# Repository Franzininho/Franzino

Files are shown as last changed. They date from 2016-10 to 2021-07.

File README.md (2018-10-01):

# Franzino (ENG)

Franzino is a low cost Arduino standalone board. As its name suggests, is a simple board that has just the basic components so you can use the ATmega328P microcontroller, both for study and for applications in projects.

Unlike standalones available in the market, the Franzino board has pinout Arduino Rev 3 and connector for easy connection of the serial interface. The ease of access to the pins of the serial interface, enables you to connect communication modules according to the needs of the project. You will be able to easily connect serial level converters such as USB, RS232, RS485 and even a Bluetooth module, without the need to use shields.

Franzino uses Arduino UNO bootloader to facilitating the upload process of your scketch. You can easily upload your sketch to Franzino board using a USB to Serial converter, following the same steps that are already used to your Arduino UNO board.

# Characteristics:

- Arduino UNO R3 pinout;
- ATmega328P Microcontroller;
- Power: 7.5 V to 20 V DC;
- Protection against reverse polarity of the supply;
- Connector for serial interface connection;
- Power on LED;
- LED connected to pin 13 for general porpouse;

# Franzino (PT)

A placa Franzino é um Arduino standalone de baixo custo. Como seu próprio nome sugere, é uma placa enxuta que possui os componentes básicos para que você possa usar o microcontrolador ATmega328, tanto para estudo quanto para a aplicações em projetos.

Diferente dos standalones disponíveis no mercado, a placa Franzino possui pinagem Arduino UNO Rev 3 e conector para fácil ligação da interface serial. A facilidade de acesso aos pinos da interface serial, possibilita que você ligue módulos de comunicação conforme a necessidade do projeto. Você conseguirá facilmente ligar conversores de níveis seriais como: USB, RS232, RS485 e até mesmo um módulo Bluetooth, sem a necessidade do uso de shields.

A Franzino usa o bootloader do Arduino UNO facilitando o processo de upload do seu scketch. Você poderá facilmente fazer o upload do seu sketch para placa usando um conversor USB/Serial, seguindo os mesmos passos que já está acostumado a fazer com a placa Arduino UNO.

## Características:

- Pinagem Padrão UNO R3
- Microcontrolador ATmega328P;
- Alimentação: 7,5 V a 20 V DC;
- Proteção contra inversão de polaridade da fonte;
- Conector para ligação de interface serial;
- LED para indicação de alimentação;
- LED conectado ao pino 13 para uso geral

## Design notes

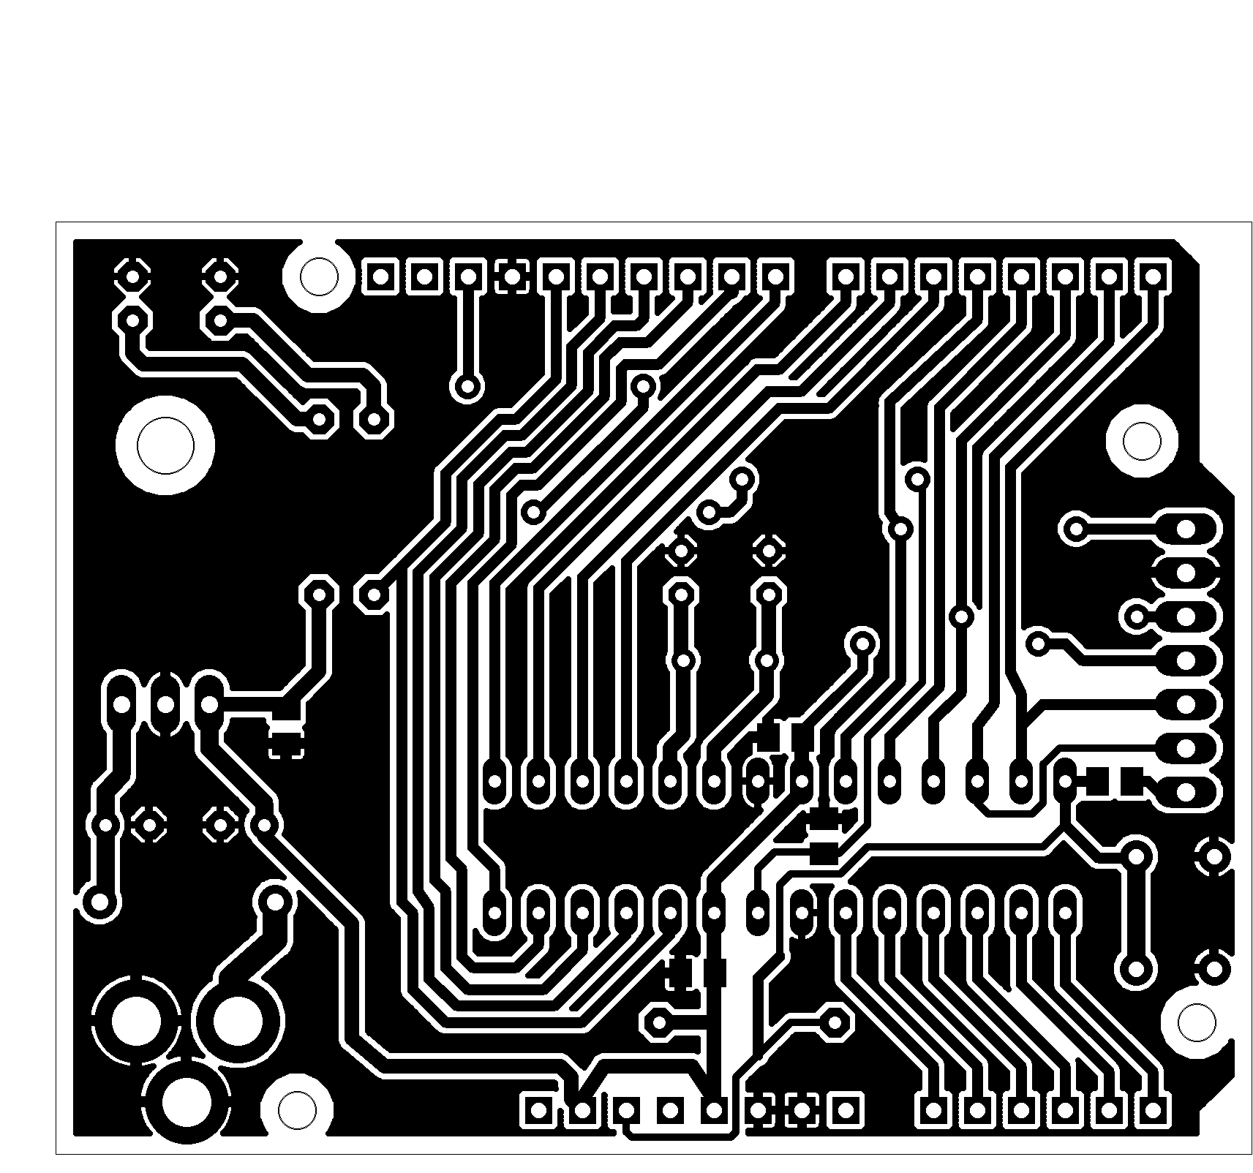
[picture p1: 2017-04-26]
Franzino - Eagle/RV0/Franzino_trilhas.png

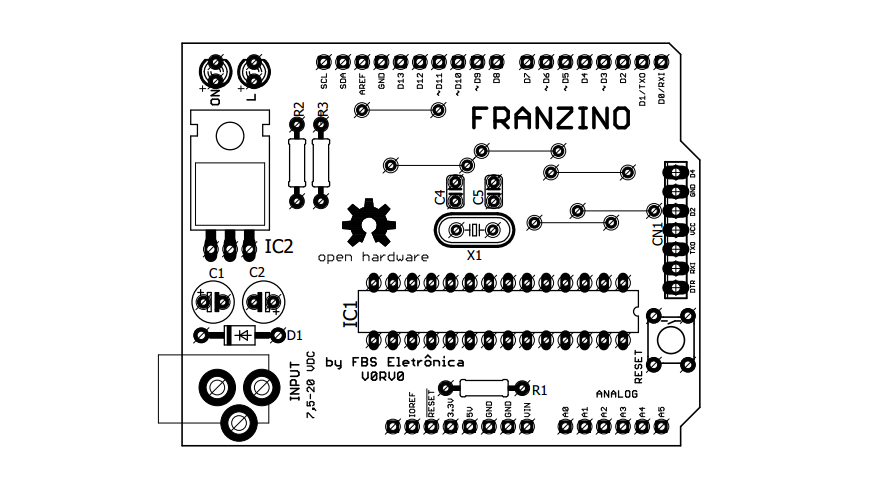
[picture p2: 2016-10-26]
Franzino - Eagle/RV0/franzino.png

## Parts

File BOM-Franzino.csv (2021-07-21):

Placa |  | Franzino
Referência | Componente | quantidade | Valor
C1 | 10uF X 50V | 1
C2 | 10uF X 50V | 1
C3 | 100nF SMD 0805 | 1
C4 | 22pF | 1
C5 | 22pF | 1
C6 | 100nF SMD 0805 | 1
C7 | 100nF SMD 0806 | 1
C8 | 100nF SMD 0807 | 1
C9 | 100nF SMD 0808 | 1
CN1 | Barra de pinos 7 vias 90° | 1
D1 | 1n4007 | 1
IC1 | Soquete 28 pinos | 1
IC2 | Regulador 7805 | 1
J1 | mini header simples 40 pinos | 1
JP1 | JUMPER FIO 10 mm | 1
JP2 | JUMPER FIO 10 mm | 1
JP3 | JUMPER FIO 10 mm | 1
JP4 | JUMPER FIO 10 mm | 1
JP5 | JUMPER FIO 10 mm | 1
JP6 | JUMPER FIO 10 mm | 1
L | LED 3 mm VERDE | 1
ON | LED 3 mm Amarelo | 1
P1 | JACK 2,1 mm | 1
R1 | Resistor 10 K 5% | 1
R2 | Resistor 1 K 5% | 1
R3 | Resistor 1 K 5% | 1
RESET | Chave Tactil 7 mm | 1
X1 | Cristal 16 MHz | 1
PCB | Placa de circuito impresso Franzino | 1

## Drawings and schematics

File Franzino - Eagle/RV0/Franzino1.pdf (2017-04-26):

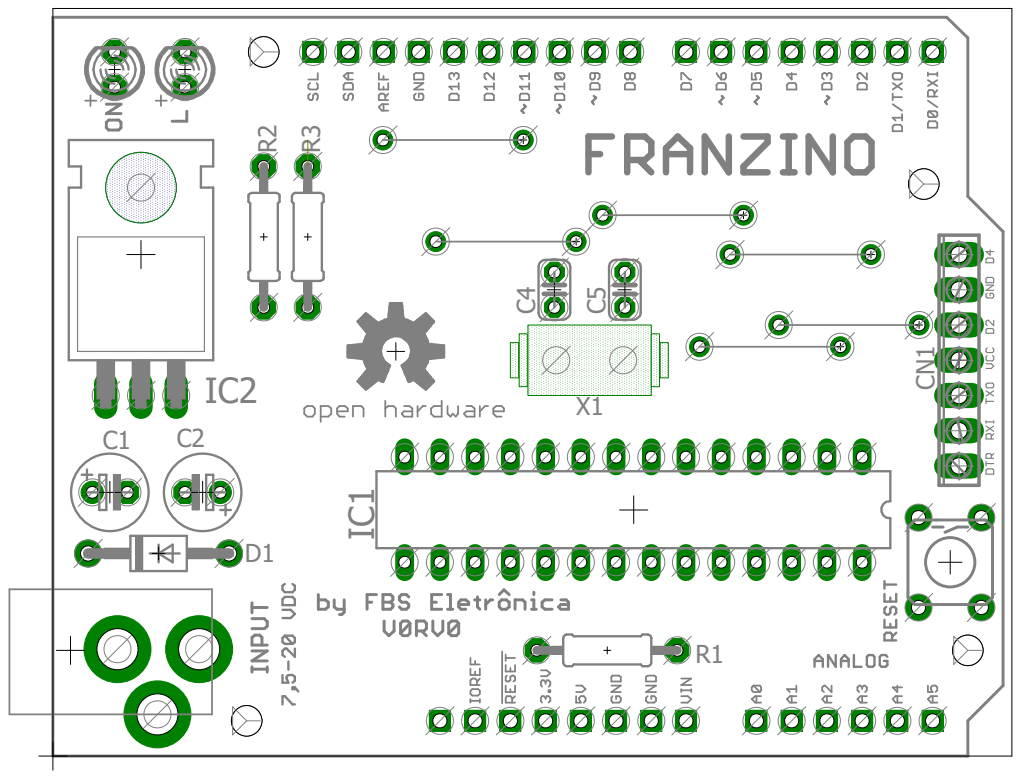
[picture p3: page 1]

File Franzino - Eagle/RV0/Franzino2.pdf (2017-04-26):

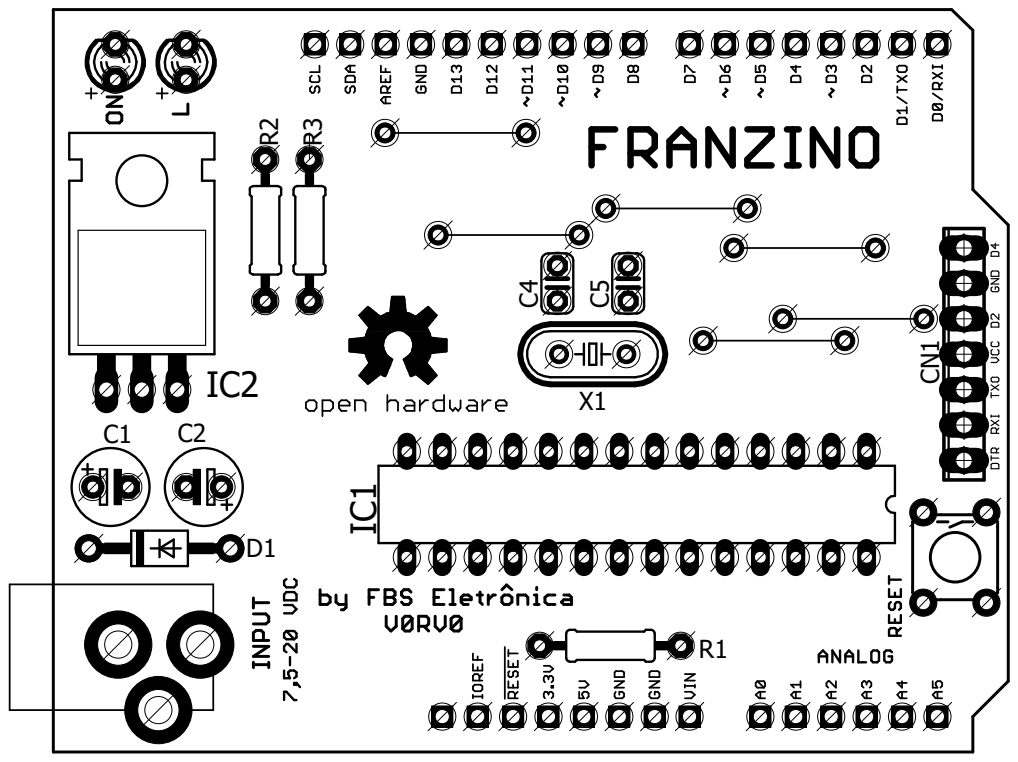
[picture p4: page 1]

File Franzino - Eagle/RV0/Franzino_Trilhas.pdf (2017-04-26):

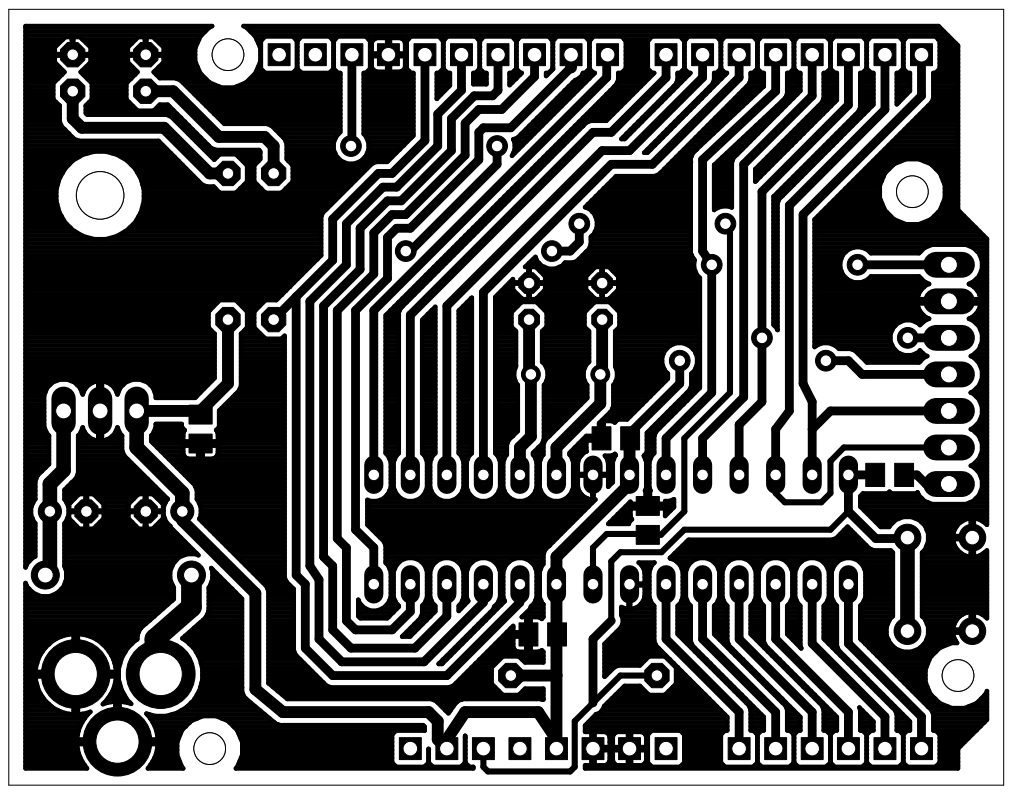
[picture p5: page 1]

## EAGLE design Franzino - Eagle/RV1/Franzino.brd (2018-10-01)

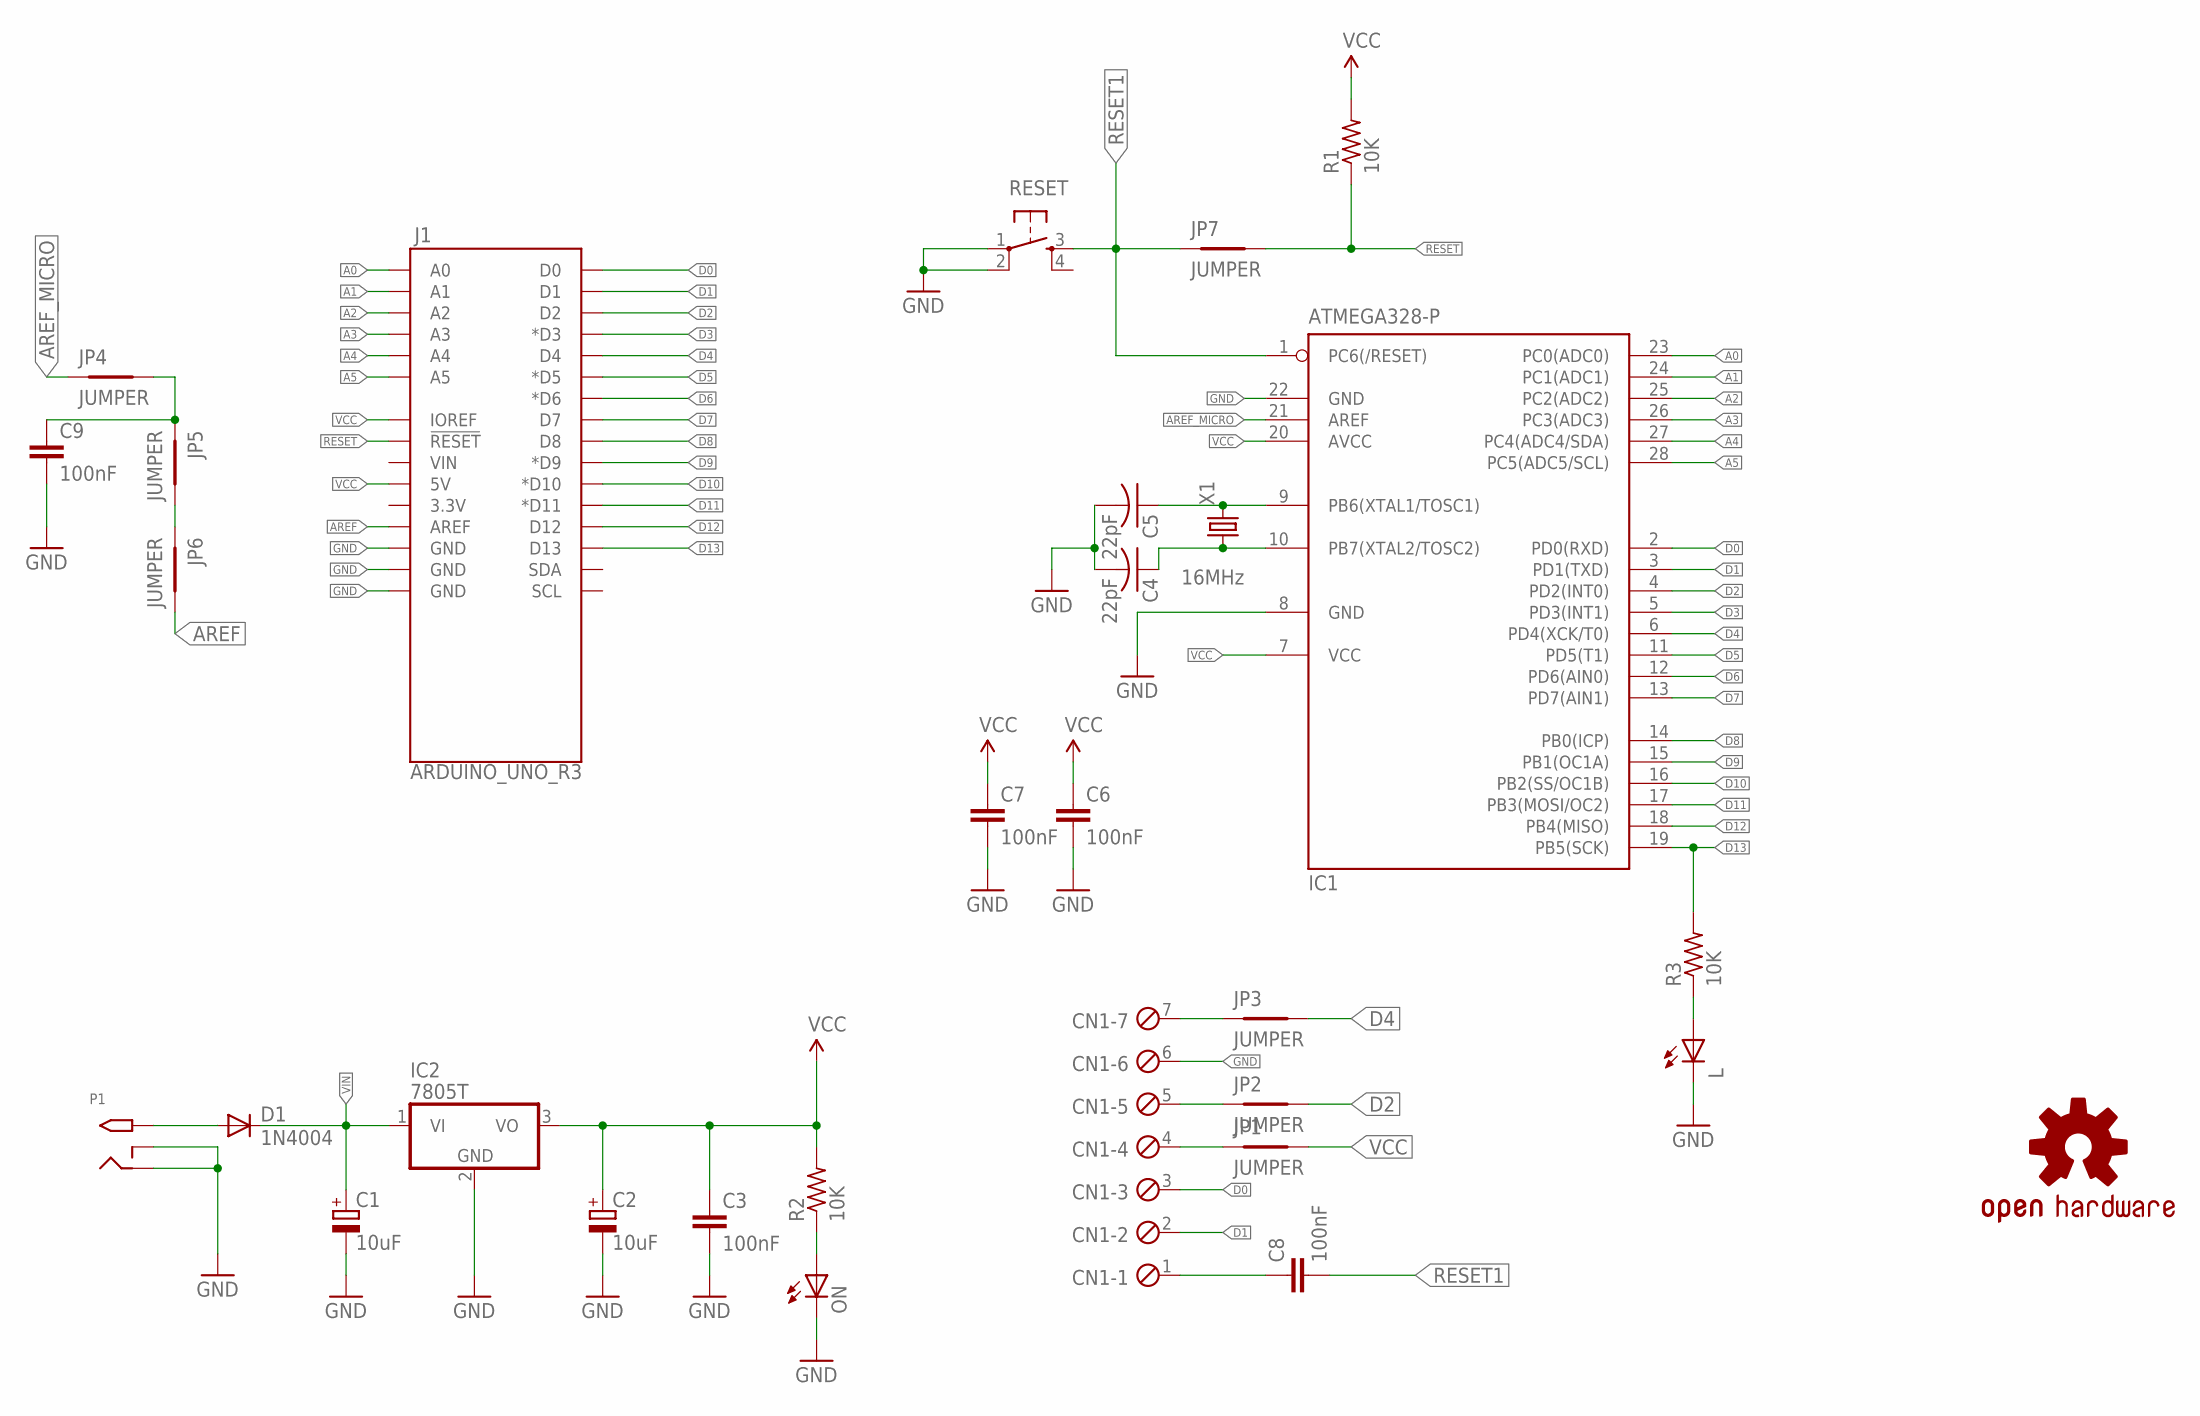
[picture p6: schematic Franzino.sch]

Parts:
C1, C2: 10uF; E2,5-6
C3, C6, C7, C8, C9: 100nF; C025-025X050
C4, C5: 22pF; C025-024X044
CN1: BARRA de PINOS 6 VIAS; 7POL254
D1: 1N4004; DO41-10
IC1: ATMEGA328-P; DIL28-3
IC2: 7805T; TO220H
J1: ARDUINO_UNO_R3; ARDUINO_UNO_R3_PINS
JP1, JP2, JP3, JP4, JP5, JP6, JP7: JUMPER; JUMP10
L: LED 3mm Amarelo; LED3MM
LOGO2: OSHW-LOGOL; OSHW-LOGO-L
ON: LED 3 mm VERDE; LED3MM
P1: 2.1MMJACKTHM; PJ-102A
R1, R2, R3: 10K; 0207/10
RESET: CHAVE TACTIL 6 mm; TACTILE-PTH
X1: 16MHz; HC49/S

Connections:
A0: IC1.23 (PC0(ADC0)), J1.A0
A1: IC1.24 (PC1(ADC1)), J1.A1
A2: IC1.25 (PC2(ADC2)), J1.A2
A3: IC1.26 (PC3(ADC3)), J1.A3
A4: IC1.27 (PC4(ADC4/SDA)), J1.A4
A5: IC1.28 (PC5(ADC5/SCL)), J1.A5
AREF: J1.AREF, JP6.2
AREF_MICRO: IC1.21 (AREF), JP4.1
D0: CN1.3, IC1.2 (PD0(RXD)), J1.D0
D1: CN1.2, IC1.3 (PD1(TXD)), J1.D1
D2: IC1.4 (PD2(INT0)), J1.D2, JP2.2
D3: IC1.5 (PD3(INT1)), J1.D3 (*D3)
D4: IC1.6 (PD4(XCK/T0)), J1.D4, JP3.2
D5: IC1.11 (PD5(T1)), J1.D5 (*D5)
D6: IC1.12 (PD6(AIN0)), J1.D6 (*D6)
D7: IC1.13 (PD7(AIN1)), J1.D7
D8: IC1.14 (PB0(ICP)), J1.D8
D9: IC1.15 (PB1(OC1A)), J1.D9 (*D9)
D10: IC1.16 (PB2(SS/OC1B)), J1.D10 (*D10)
D11: IC1.17 (PB3(MOSI/OC2)), J1.D11 (*D11)
D12: IC1.18 (PB4(MISO)), J1.D12
D13: IC1.19 (PB5(SCK)), J1.D13, R3.2
GND: C1.-, C2.-, C3.2, C4.2, C5.2, C6.2, C7.2, C9.2, CN1.6, IC1.8 (GND), IC1.22 (GND), IC2.2 (GND), J1.GND@1 (GND), J1.GND@2 (GND), J1.GND@3 (GND), L.K (C), ON.K (C), P1.RING, P1.RING_SW, RESET.1, RESET.2
unnamed: D1.A, P1.TIP
unnamed: L.A, R3.1
unnamed: C8.1, CN1.1
unnamed: CN1.4, JP1.1
unnamed: CN1.5, JP2.1
unnamed: ON.A, R2.1
unnamed: CN1.7, JP3.1
unnamed: C5.1, IC1.9 (PB6(XTAL1/TOSC1)), X1.2
unnamed: C4.1, IC1.10 (PB7(XTAL2/TOSC2)), X1.1
unnamed: C9.1, JP4.2, JP5.1
unnamed: JP5.2, JP6.1
RESET: J1.RESET@1 (!RESET!), JP7.2, R1.1
RESET1: C8.2, IC1.1 (PC6(/RESET)), JP7.1, RESET.3
VCC: C2.+, C3.1, C6.1, C7.1, IC1.7 (VCC), IC1.20 (AVCC), IC2.3 (VO), J1.5V, J1.IOREF, JP1.2, R1.2, R2.2
VIN: C1.+, D1.C, IC2.1 (VI)

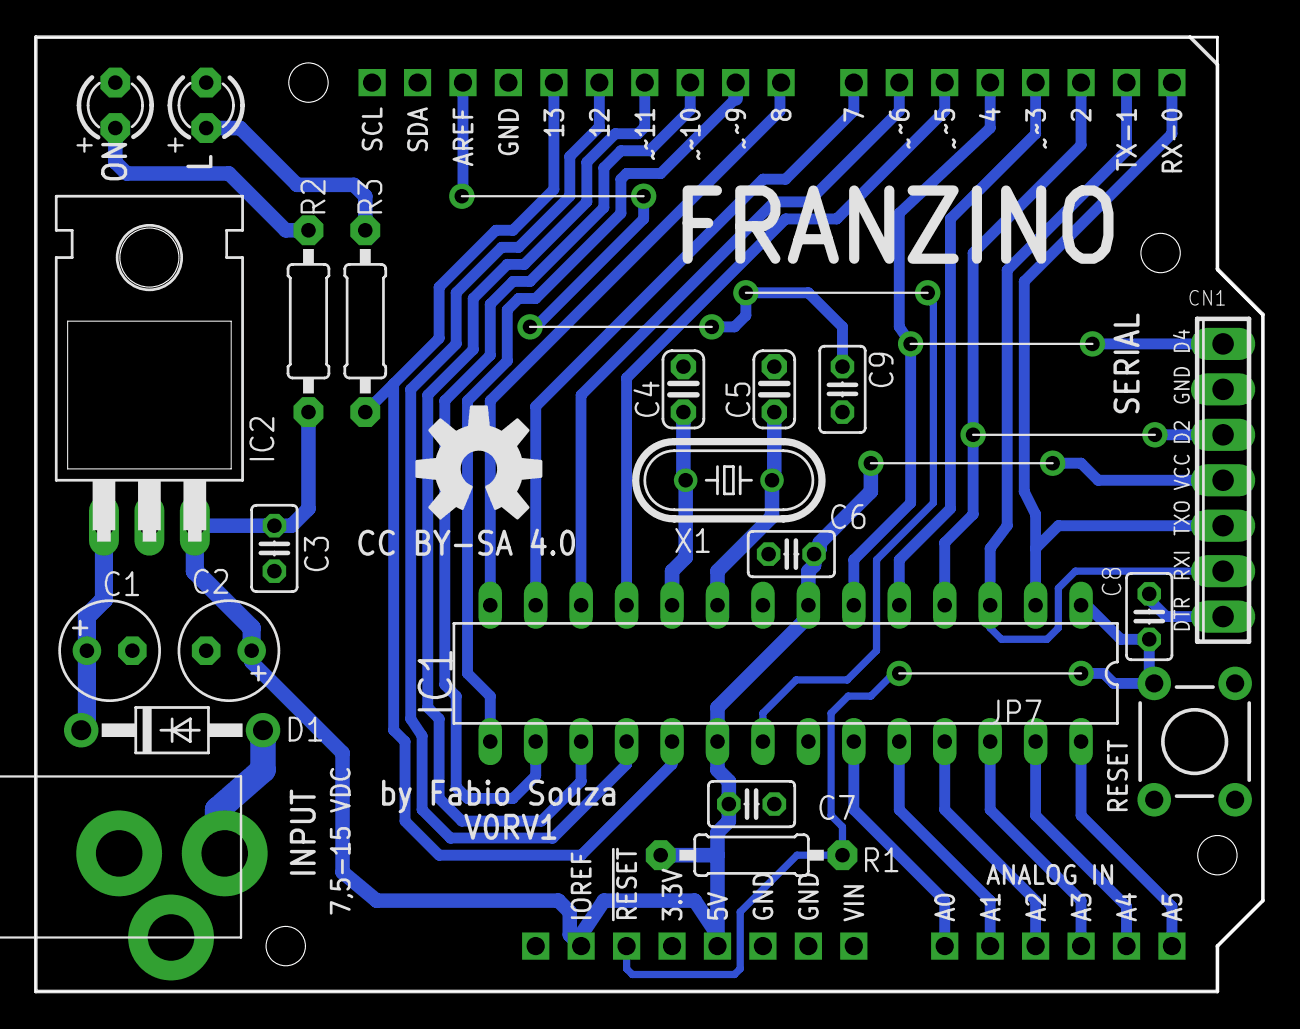
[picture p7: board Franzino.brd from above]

Board: 2 copper layers, 68.6 x 53.3 mm, 30 parts (0 on the bottom side), 38 nets.

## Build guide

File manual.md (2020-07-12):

Franzino

by Fábio Souza

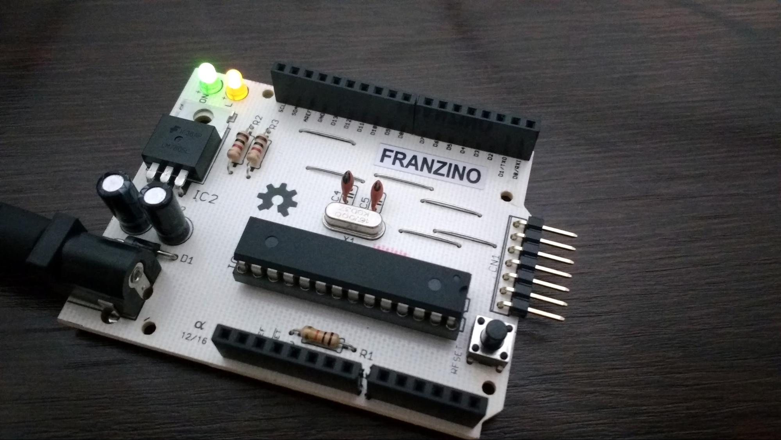
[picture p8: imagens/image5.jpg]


A placa Franzino é um Arduino standalone de baixo custo. Como seu próprio nome sugere, é uma placa enxuta que possui os componentes básicos para que você possa usar o microcontrolador ATmega328, tanto para estudo quanto para a aplicações em projetos.

Diferente dos standalones disponíveis no mercado, a placa Franzino possui pinagem Arduino UNO Rev 3 e conector para fácil ligação da interface serial. A facilidade de acesso aos pinos da interface serial, possibilita que você ligue módulos de comunicação conforme a necessidade do projeto. Você conseguirá facilmente ligar conversores de níveis seriais como: USB, RS232, RS485 e até mesmo um módulo Bluetooth, sem a necessidade do uso de shields.

A Franzino vem com o bootloader do Arduino UNO facilitando o processo de upload do seu scketch. Você poderá facilmente fazer o upload do seu sketch para placa usando um conversor USB/Serial, seguindo os mesmos passos que já está acostumado a fazer com a placa Arduino UNO.

## Características:

- Pinagem Padrão UNO R3
- Microcontrolador ATmega328P;
- Alimentação: 7,5 V a 20 V DC;
- Proteção contra inversão de polaridade da fonte;
- Conector para ligação de interface serial;
- LED para indicação de alimentação;
- LED conectado ao pino 13 para uso geral

A seguir é apresentada a pinagem para interface serial:

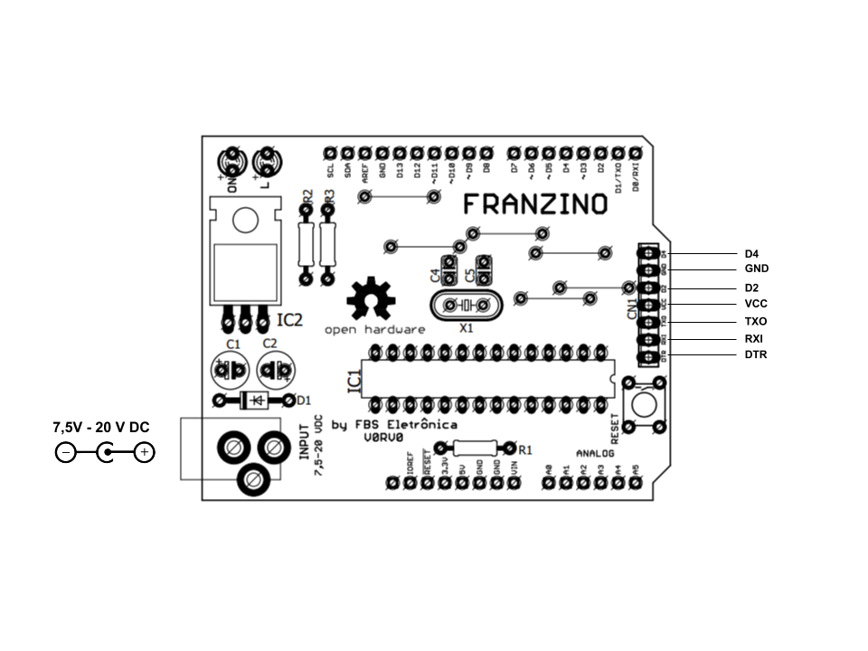
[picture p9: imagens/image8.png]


Os pino D2 e D4 podem ser utilizados para uma comunicação soft serial, como pino de controle da comunicação RS485 ou outras aplicações de entrada ou saída.

Outra vantagem interessante é que as linhas de alimentação(VCC e GND) também estão disponíveis nesse conector.

Assim, com esse conector você pode facilmente ligar um  conversor USB/Serial para comunicação com um computador, seja para upload dos sketchs quanto para troca de informações.

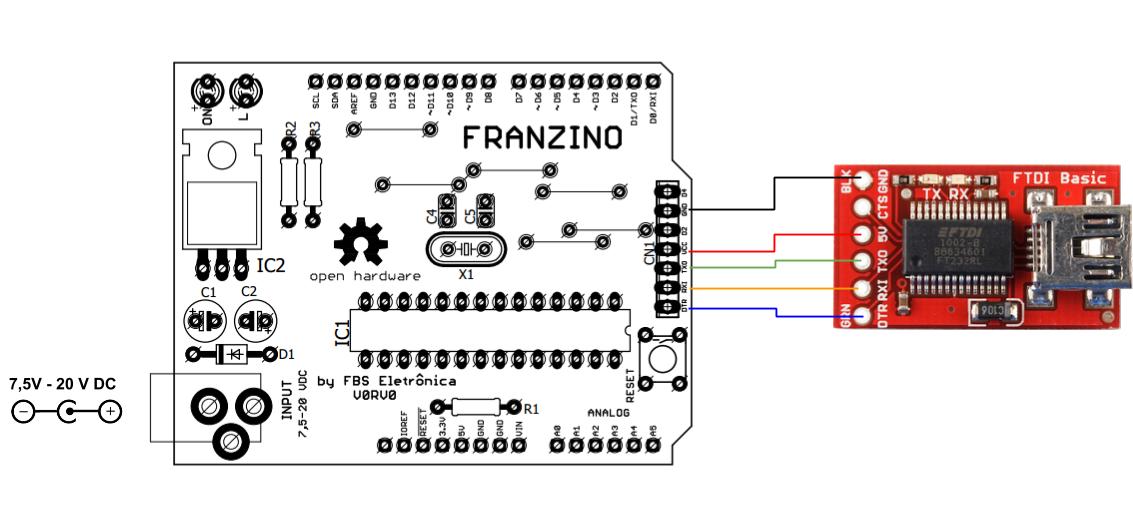
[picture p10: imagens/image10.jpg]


Se o seu projeto não necessitar da comunicação USB/Serial durante o seu funcionamento, você poderá usar o mesmo conversor para fazer upload em outra Franzinos.

Algumas aplicações necessitam de comunicação serial no padrão RS232. Dessa forma você pode ligar facilmente um conversor TTL/RS232.

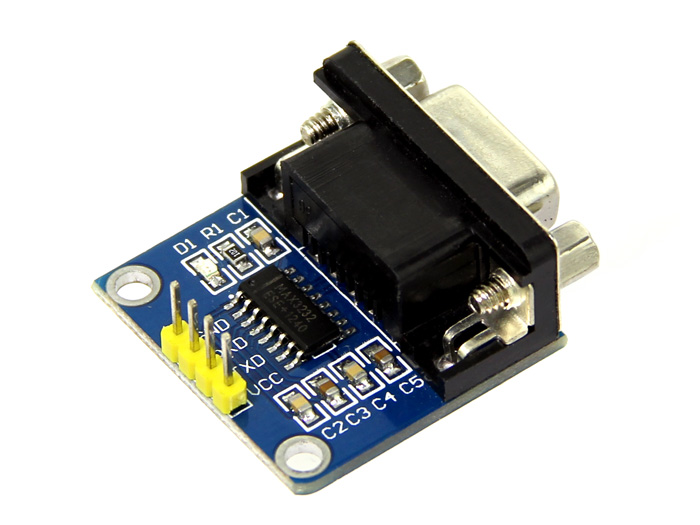
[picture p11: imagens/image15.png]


Também é comum aplicações que necessitem da comunicação RS485. Para isso você pode facilmente ligar um módulo conversor TTL/RS485:

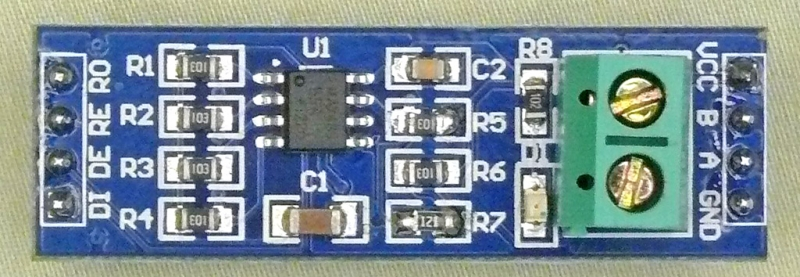
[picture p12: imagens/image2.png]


Outra aplicação interessante para comunicação e o uso de módulos Bluetooth. Esse tipo de módulo pode ser facilmente ligado a Franzino tanto para uso dos pinos padrões de comunicação TX e RX quanto para comunicação soft serial:

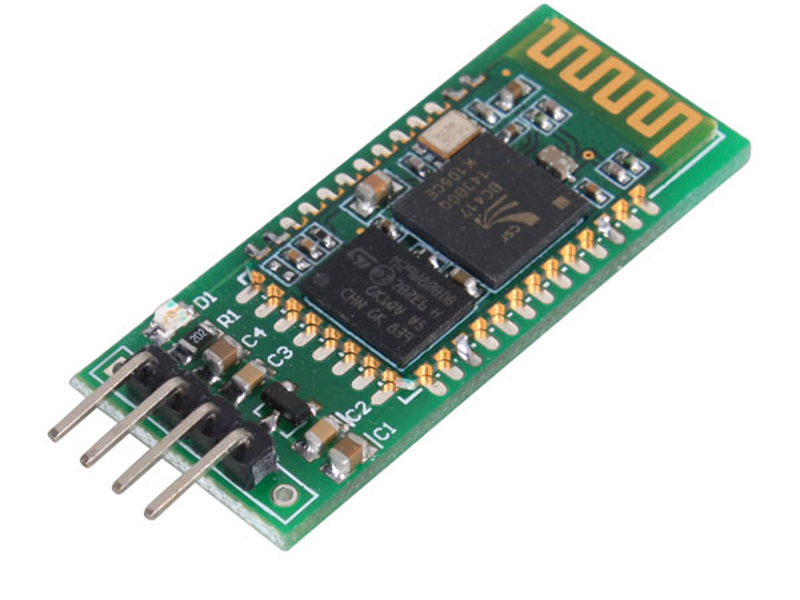
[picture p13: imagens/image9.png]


Como observado acima, há muitas possibilidades de comunicações e você pode facilmente ligar outros módulos para diversas aplicações conforme sua necessidade.

## Limitações da Franzino

A Franzino é uma placa standalone que possui diversas vantagens. Porém como foi desenvolvida em face simples e com o mínimo de componente necessários para o uso do microcontrolador, possui algumas limitações em relação ao Arduino UNO, que são:

- Não há regulador 3,3 V, dessa forma o pino 3.3V não está conectado;
- O pino Vin não está conectado a alimentação;
- Os pinos SCL e SDA não estão conectados as pinos A4 e A5;
- Não possui conversor USB/Serial
- Precisa de um conversor USB/Serial para upload dos sketchs

## Alimentação

A Franzino pode ser alimentada das seguintes formas:

- Conector P4 com tensão de 7,5 V a 20 V como positivo no centro;
- Pino 5V e GND - tensão de alimentação fixa em 5 VDC
- Através nos pinos VCC e GND disponíveis conector de expansão serial;

### Atenção

Não LIGAR o VCC do conversor USB/SERIAL a placa se a fonte externa estiver ligada. Nesse caso ligar apenas os pinos DTR, RXI, TXO e GND.

## Blink com a Franzino

Upload via conversor USB/SERIAL

Para fazer o famoso blink com a Franzino, primeiro é necessário ligar o conversor USB/Serial a placa, como exibido na figura abaixo:



Selecione na IDE do Arduino a Placa Arduino/Genuino UNO. Também selecione a porta COM que foi criada ao ser inserido o conversor USB/SERIAL:

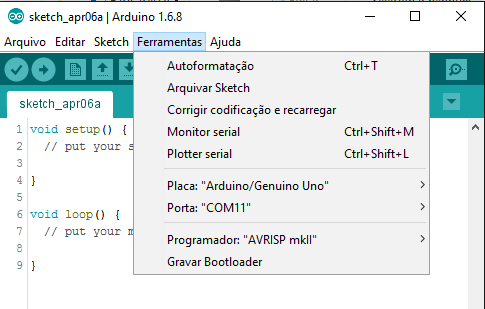
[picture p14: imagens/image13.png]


Faça o UPLOAD:

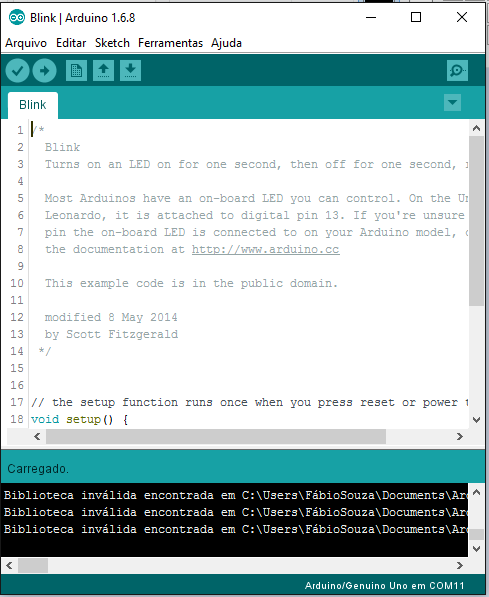
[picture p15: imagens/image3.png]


## Gravando a Franzino com um placa Arduino UNO

Se você não possui um conversor USB/Serial você pode gravar a Franzino através de um Arduino. Para isso vamos configurar a placa Arduino UNO com programador.

Escolha a opção ArduinoISP, conforme figura abaixo:

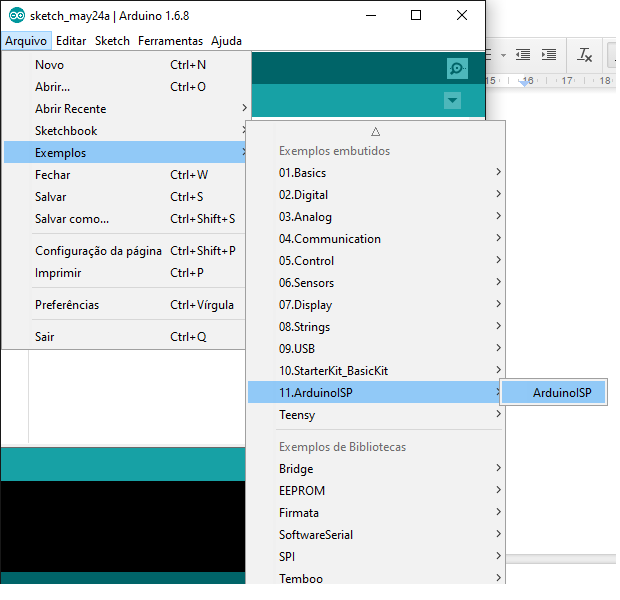
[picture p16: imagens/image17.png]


Faça o upload para a placa Arduino UNO que será usada como programador.

Feito o UPLOAD, agora vamos as conexões do Arduino UNO na Franzino:

- Ligue o pino RESET da FRANZINO ao pino 10 do Arduino
- Ligue o pino 11 da FRANZINO ao pino 11 do Arduino
- Ligue o pino 12 da FRANZINO ao pino 12 do Arduino
- Ligue o pino 13 da FRANZINO ao pino 13 do Arduino
- Ligue o pino 5V da FRANZINO no pino 5V do Arduino
- Ligue o pino GND da FRANZINO ao GND do Arduino

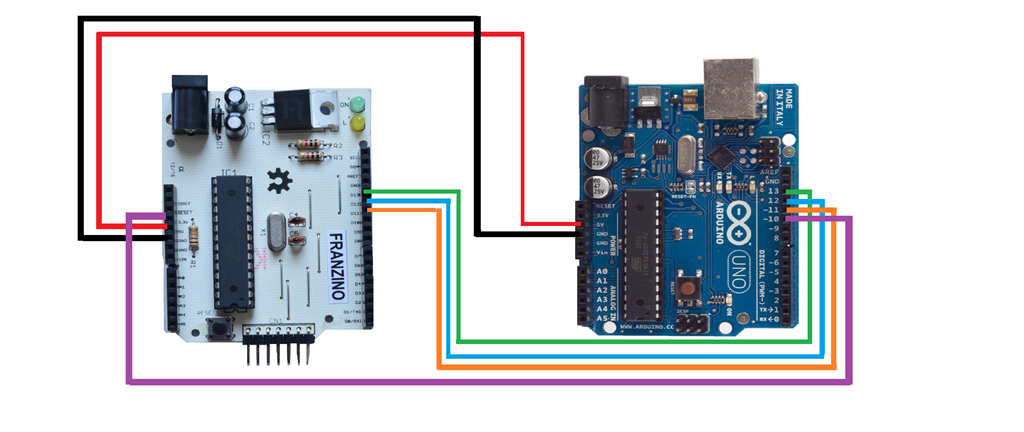
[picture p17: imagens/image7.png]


## Configurando o avrdude ( se estiver usando o ATmega328 e não o ATmega328P)

A versão 0 da Franzino vem com o ATmega328-PU, dessa forma precisamos configurar o avrdude para gravar esse microcontrolador. Na pasta do arduino acesse: C:\arduino-1.6.8\hardware\tools\avr\etc, abra o arquivo avrdude.conf

Procure a assinatura do ATMEGA328P:

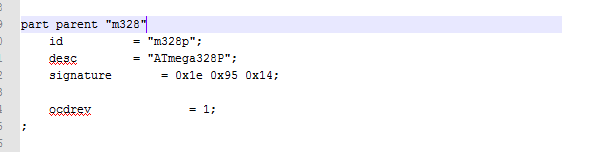
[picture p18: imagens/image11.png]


Troque a assinatura por:

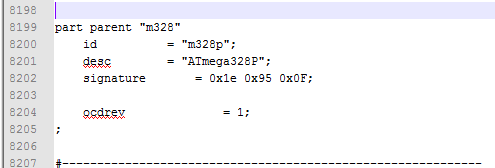
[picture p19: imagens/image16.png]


Salve o arquivo.

Após a gravação, volte a assinatura para o valor original:  signature= 0x1e 0x95 0x0F;
UPLOAD de Sketchs usando a Arduino UNO

Pronto, agora abra o programa que será gravado na Franzino. Para esse exemplo vamos usar o exemplo Blink, mas você poderá fazer esse procedimento para gravar suas aplicações;

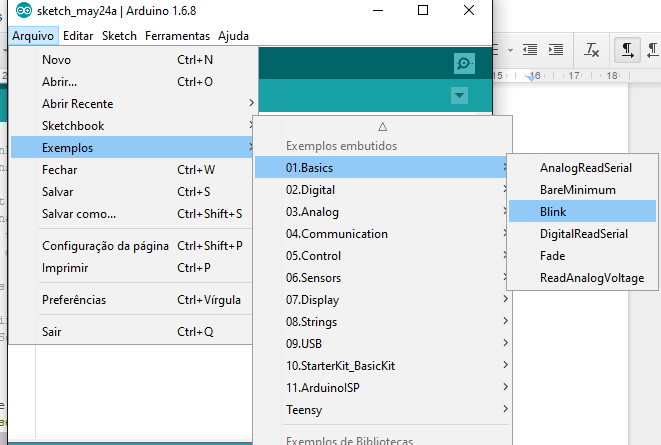
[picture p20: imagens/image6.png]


Agora vamos preparar para gravação. Configure o Programador como ArduinoISP:

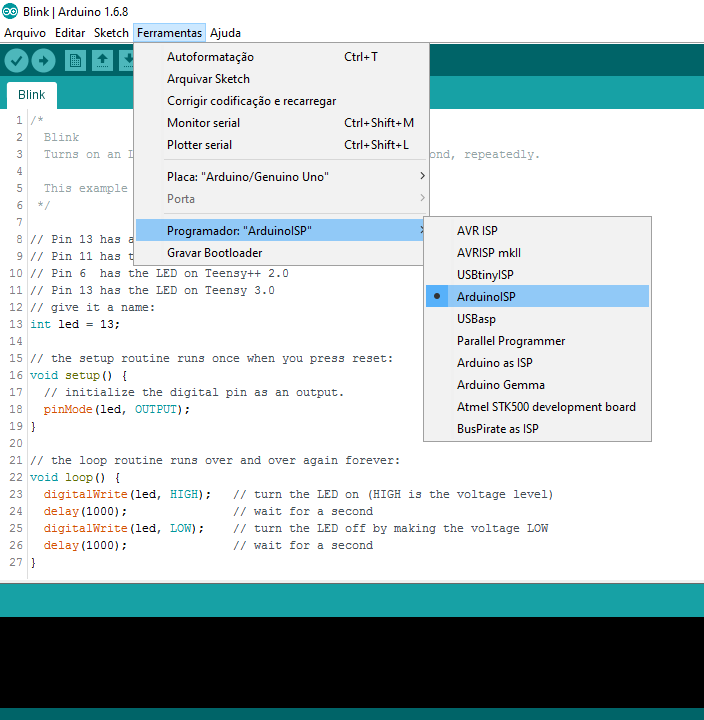
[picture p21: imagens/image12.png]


Pronto, agora é só fazer o UPLOAD para a Franzino:

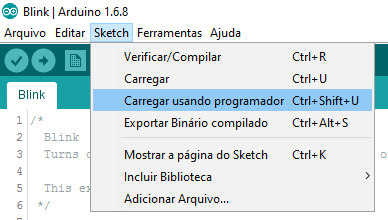
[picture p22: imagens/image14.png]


## Esquema elétrico da placa

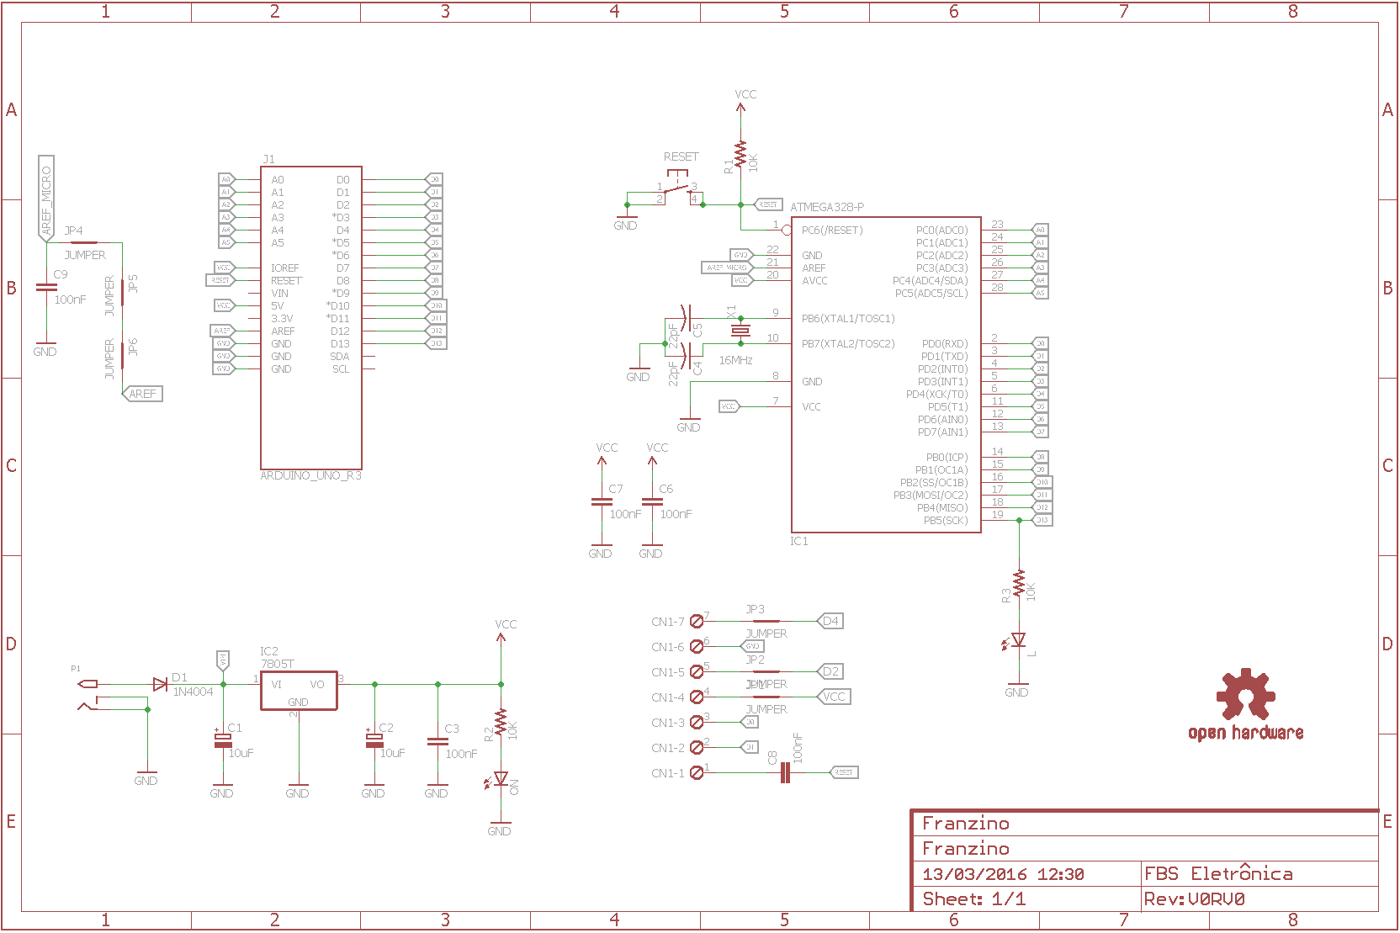
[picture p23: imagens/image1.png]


## Layout

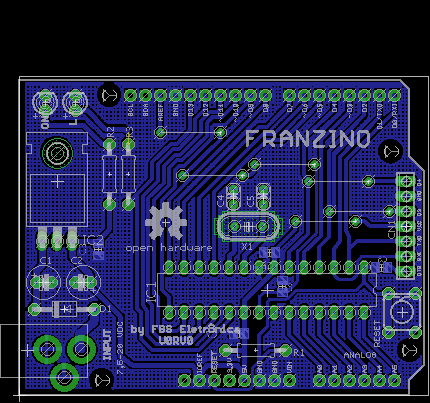
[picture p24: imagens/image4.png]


Todos os arquivos de projeto estão disponíveis no Github: https://github.com/FBSeletronica/Franzino

### Referências

Artigo no Embarcados: https://www.embarcados.com.br/franzino-open-hardware-de-baixo-custo/

Arquivos no GITHUB:
https://github.com/FBSeletronica/Franzino

Controle de revisões do Manual

RV0 - primeiro documento
RV1 - inserido programação através do Arduino UNO
RV2 - Links

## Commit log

2016-10-26 Franzino
    V0 RV1
    [Franzino.brd, Franzino.sch]
2017-04-26 update - Pordução processo termico
    [Franzino.brd]
2017-11-20 RV1
    Trocado capacitores de SMD por PTH
    Melhora no Silk
    [Franzino.brd, Franzino.sch]
2018-10-01 atualização RV1
    [Franzino.brd, Franzino.sch]
2021-07-21 Lista de componentes
    [BOM-Franzino.csv]

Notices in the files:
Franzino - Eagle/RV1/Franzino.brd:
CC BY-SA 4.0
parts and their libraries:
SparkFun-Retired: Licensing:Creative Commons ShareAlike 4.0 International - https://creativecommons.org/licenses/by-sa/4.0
